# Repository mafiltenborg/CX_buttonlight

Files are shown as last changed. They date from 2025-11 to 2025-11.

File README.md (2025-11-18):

# What's this?
Incandescent bulbs are used in the most bizarre places in older cars - and they're often hard to replace when they burn out.
This repo holds an absolutely tiny pcb with LEDs, designed to replace one of these specialty bulb-PITAs - once and for all!

# Which & where
The particular bulb being replicated/upgraded is located inside the toggle-contacts for eg electric windows or demister switch in the Citroen CX S2 (late model '86 onwards). Replacing requires disassembly and fairly good motorskills on your part. The design uses 0805 SMDs, making it, well, possible as least. I'm too old for 0402...

# How
To replace, get hold of a number of the little PCBs (17 x 5,5mm) and solder them up. 
Next, for every contact you want to upgrade, do
* Open up your contact and extract the yellow opaque plastic thingamabob.
* Remove the burnt-out bulb and slide in a LED-replacement circuit. Re-wire the yellow thingamabob.
* Plonk in the thingamabob and do a test run. If it doesn't light up, try turning it 180 degrees - polarity matters...

Further tweaks may include modding the value of R2 to get a sensible light output. LEDs are in fact quite bright and 'much' may not be the right choice for you. The circuit is not designed for power hungry LEDs as it uses a linear regulator. 

LEDs differ. To figure out the value of R2, use the formula

Vout = 1.25 * (1 + R2/R1)

To calculate.

Don't modify R1, as this may create instability.

-----------------------
Nov. 2025 update: This design has sparked development of a more userfriendly successor. More light and less hassle too. If interested, have a look [here](https://github.com/mafiltenborg/CX-buttonlight_v2)...

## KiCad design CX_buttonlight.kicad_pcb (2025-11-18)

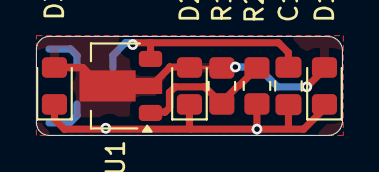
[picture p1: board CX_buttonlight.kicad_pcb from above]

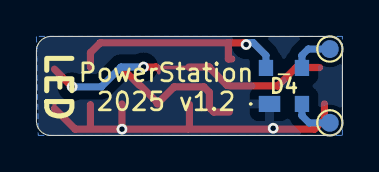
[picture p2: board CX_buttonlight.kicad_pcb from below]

Board: 2 copper layers, 17.0 x 5.5 mm, 10 parts (3 on the bottom side), 6 nets.

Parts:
C1: 100nF; C_0805_2012Metric_Pad1.18x1.45mm_HandSolder
D1, D2, D3: LED; LED_0805_2012Metric_Pad1.15x1.40mm_HandSolder
D4: BAS4002ARPPE6327HTSA1
Ground1: Ground; TestPoint_Pad_D1.0mm
R1: 470R; R_0805_2012Metric_Pad1.20x1.40mm_HandSolder
R2: 220R; R_0805_2012Metric_Pad1.20x1.40mm_HandSolder
Supply1: 12V; TestPoint_Pad_D1.0mm
U1: LM317L_SOT-89; SOT-89-3

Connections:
GND: C1.2, D1.1 (K), D2.1 (K), D3.1 (K), D4.1 (-), R2.1
unnamed: D1.2 (A), D2.2 (A), D3.2 (A), R1.2, U1.2 (VO)
unnamed: C1.1, D4.4 (+), U1.3 (VI)
unnamed: D4.2 (~_1), Supply1.1
unnamed: D4.3 (~_2), Ground1.1
unnamed: R1.1, R2.2, U1.1 (ADJ)

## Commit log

2025-10-21 v1.1 - med beskyttelsesdiode
    [CX_buttonlight.kicad_sch]
2025-10-24 updated design (tweaks + specs), sent to JLCPCB
    [CX_buttonlight.kicad_pcb, CX_buttonlight.kicad_sch]
2025-11-18 Tweaks og tekster
    [CX_buttonlight.kicad_pcb, CX_buttonlight.kicad_sch]
